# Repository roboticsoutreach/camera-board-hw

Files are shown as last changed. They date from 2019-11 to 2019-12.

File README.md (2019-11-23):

# Hardware design files for the camera module

The Camera Board is a project that aims to find a hardware replacement for webcams.

The current Webcams have a slow shutter speed and the image quality is not great, this means that the robots cannot take images while moving, and can lead to some big issues if the lighting is not right.

Using Raspberry pi camera's we can improve the shutter speed, which will hopefully allow for image processing on the move. We can also have a compute module 3 which deals with all of the image processing so that the robot "brain" doesn't have to. It will also allow for 2 cameras, one which can either be attached to the board directly or over a HDMI cable, and the other will be just over HDMI. This will allow for taking images in different directions, or having a forward facing camera and a turning camera, or could be used for stereo vision.

The first prototype for this board was made at the end of the 2018-2019 academic year, and did not work due to impedance matching issues on the HDMI lines, which meant we could not get a signal out of the Pi. This can likely be fixed by using a 4 layer stackup with a tuned impedance, this way we can ensure that the signal does not destructively interfere with itself in the cable by tuning the width of the PCB traces and the distance between the signals of a differential pair.

The Schematic has currently been updated and is now licenced under CC by SA, where previously it didn't have a license. The next step is to reoute the PCB, and order it so that a second prototype can be tested, if that works, then some of the IO will be removed, and the PCB will be made as small as possible. At this point the PCB will be ready for manufacture.

Once we have a working prototype, work will start on the software which will allow the compute module to do the image processing, and send the data over USB to the "brain" of the computer when requested. The specification and architecture of the software are not yet decided.

This project is currently being led by Joe Morton and Daniel Hobson, so if you would like to get involved with any aspect of this project, please speak to one of us.

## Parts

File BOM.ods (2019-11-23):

QTY | supplier | supplier number | link |  | price each | Qty to be ordered
8 | digikey | 490-13247-1-ND | https://www.digikey.co.uk/product-detail/en/murata-electronics-north-america/GRM188R60J476ME15D/490-13247-1-ND/5877455 | 47u | 0.32 | 20 | 6.4
16 | digikey | 1276-1000-6-ND | https://www.digikey.co.uk/product-detail/en/samsung-electro-mechanics/CL10B104KB8NNNC/1276-1000-6-ND/3891514 | 100n | 0.025 | 40 | 1
4 | digikey | 1276-1119-1-ND | https://www.digikey.co.uk/product-detail/en/samsung-electro-mechanics/CL10A106MQ8NNNC/1276-1119-1-ND/3889205 | 10u | 0.099 | 10 | 0.99
1 | digikey | 1276-7076-1-ND | https://www.digikey.co.uk/product-detail/en/samsung-electro-mechanics/CL10A226MO7JZNC/1276-7076-1-ND/7320718 | 22u | 0.62 | 4 | 2.48
2 | digikey | 1276-1036-1-ND | https://www.digikey.co.uk/product-detail/en/samsung-electro-mechanics/CL10A105KQ8NNNC/1276-1036-1-ND/3889122 | 1u | 0.022 | 10 | 0.22
12 | digikey | SML-H12P8TT86CCT-ND | https://www.digikey.co.uk/product-detail/en/rohm-semiconductor/SML-H12P8TT86C/SML-H12P8TT86CCT-ND/9090488 | LED | 0.2068 | 28 | 5.7904
2 | digikey | 475-3547-1-ND | https://www.digikey.co.uk/product-detail/en/osram-opto-semiconductors-inc/LRTBGVTG-U5V5-1-A5B5-29-S9T9-49-20-R33-B/475-3547-1-ND/8827186 | RGB LED | 0.68 | 5 | 3.4
1 | RS | 647-8263 | https://uk.rs-online.com/web/p/resettable-surface-mount-fuses/6478263/ | 2A poly fuse | 0.329 | 10 | 3.29
1 | RS | 897-1262 | https://uk.rs-online.com/web/p/pcb-terminal-blocks/8971262/ | camcon |  |  | 0
2 | digikey | 609-4050-1-ND | https://www.digikey.co.uk/product-detail/en/amphenol-icc-fci/10103594-0001LF/609-4050-1-ND/2350357 | uUSB | 0.58 | 5 | 2.9
2 | digikey | 609-1906-1-ND | https://www.digikey.co.uk/product-detail/en/amphenol-icc-fci/SFW15R-2STE1LF/609-1906-1-ND/1003189 | FFC | 0.37 | 5 | 1.85
1 | digikey | H11856CT-ND | https://www.digikey.co.uk/product-detail/en/hirose-electric-co-ltd/DF37NC-30DS-0.4V-51/H11856CT-ND/2230656 | camera connector | 0.76 | 3 | 2.28
3 | digikey | 732-2739-1-ND | https://www.digikey.co.uk/product-detail/en/wurth-electronics-inc/685119136923/732-2739-1-ND/2508681 | hdmi | 2.3 | 6 | 13.8
2 | digikey | 952-2262-ND | https://www.digikey.co.uk/product-detail/en/harwin-inc/M20-9990246/952-2262-ND/3728226 | conn | 0.08 | 4 | 0.32
1 | digikey | 732-5316-ND | https://www.digikey.co.uk/product-detail/en/wurth-electronics-inc/61300311121/732-5316-ND/4846825 | conn | 0.1 | 2 | 0.2
1 | digikey | 732-5317-ND | https://www.digikey.co.uk/product-detail/en/wurth-electronics-inc/61300411121/732-5317-ND/4846827 | conn | 0.14 | 2 | 0.28
1 | digikey | 732-5318-ND | https://www.digikey.co.uk/product-detail/en/wurth-electronics-inc/61300511121/732-5318-ND/4846831 | conn | 0.2 | 2 | 0.4
1 | digikey | 732-5319-ND | https://www.digikey.co.uk/product-detail/en/wurth-electronics-inc/61300611121/732-5319-ND/4846833 | conn | 0.26 | 2 | 0.52
1 | digikey | A26589-ND | https://www.digikey.co.uk/product-detail/en/te-connectivity-amp-connectors/3-87227-0/A26589-ND/353082 | conn | 11.32 | 2 | 22.64
2 | digikey | 445-6760-1-ND | https://www.digikey.co.uk/product-detail/en/tdk-corporation/MLZ2012N4R7LT000/445-6760-1-ND/2523581 | 4.7uH | 0.1 | 5 | 0.5
4 | digikey | 445-2986-1-ND | https://www.digikey.com/product-detail/en/MPZ1608D300BTA00/445-2986-1-ND/1084529 | ferrite | 0.079 | 10 | 0.79
1 | digikey | SDR0805-3R3MLCT-ND | https://www.digikey.co.uk/product-detail/en/bourns-inc/SDR0805-3R3ML/SDR0805-3R3MLCT-ND/3043665 | 3.3uH | 0.55 | 3 | 1.65
1 | digikey | A114854-ND | https://www.digikey.co.uk/product-detail/en/te-connectivity-amp-connectors/1473149-4/A114854-ND/1890696 | conn | 2.61 | 2 | 5.22
1 | digikey | EM6K34T2CRCT-ND | https://www.digikey.co.uk/product-detail/en/rohm-semiconductor/EM6K34T2CR/EM6K34T2CRCT-ND/5042498 | EM6K34T2CR | 0.31 | 2 | 0.62
5 | digikey | DMG1012UW-7DICT-ND | https://www.digikey.co.uk/product-detail/en/diodes-incorporated/DMG1012UW-7/DMG1012UW-7DICT-ND/2183242 | DMG1012W-7 | 0.265 | 10 | 2.65
3 | digikey | DMMT5401-FDICT-ND | https://www.digikey.co.uk/product-detail/en/diodes-incorporated/DMMT5401-7-F/DMMT5401-FDICT-ND/717881 | DMMT5401-7 | 0.34 | 6 | 2.04
3 | digikey | DMG2305UX-13DICT-ND | https://www.digikey.co.uk/product-detail/en/diodes-incorporated/DMG2305UX-13/DMG2305UX-13DICT-ND/4251589 | DMG2305UX | 0.33 | 6 | 1.98
14 | digikey | RMCF0603ZT0R00CT-ND | https://www.digikey.co.uk/product-detail/en/stackpole-electronics-inc/RMCF0603ZT0R00/RMCF0603ZT0R00CT-ND/1943218 | 0 ohm | 0.0088 | 30 | 0.264
1 | digikey | RG16P100BCT-ND | https://www.digikey.co.uk/product-detail/en/susumu/RG1608P-101-B-T5/RG16P100BCT-ND/1240831 | 100 ohm | 0.31 | 4 | 1.24
5 | digikey | YAG1235CT-ND | https://www.digikey.co.uk/product-detail/en/yageo/RT0603BRD07100KL/YAG1235CT-ND/4340588 | 100k | 0.249 | 12 | 2.988
7 | digikey | RNCP0603FTD10K0CT-ND | https://www.digikey.co.uk/product-detail/en/stackpole-electronics-inc/RNCP0603FTD10K0/RNCP0603FTD10K0CT-ND/2240478 | 10k | 0.05 | 16 | 0.8
18 | digikey | 311-470HRCT-ND | https://www.digikey.co.uk/product-detail/en/yageo/RC0603FR-07470RL/311-470HRCT-ND/730203 | 470 ohm | 0.018 | 40 | 0.72
2 | digikey | RMCF0603FT1K80CT-ND | https://www.digikey.co.uk/product-detail/en/stackpole-electronics-inc/RMCF0603FT1K80/RMCF0603FT1K80CT-ND/1943005 | 1.75k | 0.07 | 5 | 0.35
1 | digikey | RMCF0603FT27K0CT-ND | https://www.digikey.co.uk/product-detail/en/stackpole-electronics-inc/RMCF0603FT27K0/RMCF0603FT27K0CT-ND/1943083 | 27k | 0.07 | 4 | 0.28
1 | digikey | RMCF0603FT56K2CT-ND | https://www.digikey.co.uk/product-detail/en/stackpole-electronics-inc/RMCF0603FT56K2/RMCF0603FT56K2CT-ND/1943105 | 56.2k | 0.07 | 4 | 0.28
6 | digikey | 311-47.0KHRCT-ND | https://www.digikey.co.uk/product-detail/en/yageo/RC0603FR-0747KL/311-47.0KHRCT-ND/730200 | 47k | 0.018 | 15 | 0.27
1 | digikey | 450-1650-ND | https://www.digikey.co.uk/product-detail/en/te-connectivity-alcoswitch-switches/1825910-6/450-1650-ND/1632536 | tactile switch | 0.07 | 2 | 0.14
1 | digikey | 296-44844-1-ND | https://www.digikey.co.uk/product-detail/en/texas-instruments/TPS563208DDCR/296-44844-1-ND/6205060 | TPS563208 | 1.01 | 2 | 2.02
1 | digikey | PAM2306AYPKEDICT-ND | https://www.digikey.co.uk/product-detail/en/diodes-incorporated/PAM2306AYPKE/PAM2306AYPKEDICT-ND/7794266 | PAM2306AYPKE | 0.55 | 2 | 1.1
1 | digikey | LTC3406ES5-1.2#TRMPBFCT-ND | https://www.digikey.co.uk/product-detail/en/linear-technology-analog-devices/LTC3406ES5-1.2-TRMPBF/LTC3406ES5-1.2-TRMPBFCT-ND/3830391 | LTC3406ES5-1.2 | 3.53 | 2 | 7.06
1 | digikey | 296-28307-1-ND | https://www.digikey.co.uk/product-detail/en/texas-instruments/TS3DDR3812RUAR/296-28307-1-ND/2609818 | TS3DDR3812RUAR | 3.41 | 2 | 6.82
1 | digikey | 296-39282-1-ND | https://www.digikey.co.uk/product-detail/en/texas-instruments/TLV70228DBVR/296-39282-1-ND/5143273 | TLV70228 | 0.38 | 2 | 0.76
1 | digikey | 893-1140-1-ND | https://www.digikey.co.uk/product-detail/en/torex-semiconductor-ltd/XC6222B181MR-G/893-1140-1-ND/2138331 | XC6222B181MR-G | 0.66 | 2 | 1.32
1 | digikey | 497-15383-1-ND | https://www.digikey.co.uk/product-detail/en/stmicroelectronics/LSM6DS3TR/497-15383-1-ND/5180534 | LSM6DS3 | 2.25 | 2 | 4.5
1 | digikey | 497-12167-1-ND | https://www.digikey.co.uk/product-detail/en/stmicroelectronics/HDMIULC6-4SC6Y/497-12167-1-ND/2826775 | HDMIULC6-4SC6 | 1.41 | 2 | 2.82
1 | digikey | AP2331SA-7DICT-ND | https://www.digikey.co.uk/product-detail/en/diodes-incorporated/AP2331SA-7/AP2331SA-7DICT-ND/2792457 | AP2331W | 0.29 | 2 | 0.58
1 | digikey | FSUSB42UMXCT-ND | https://www.digikey.co.uk/product-detail/en/on-semiconductor/FSUSB42UMX/FSUSB42UMXCT-ND/1642629 | FSUSB42UMX | 0.44 | 2 | 0.88
1 | digikey | A118230CT-ND | https://www.digikey.co.uk/product-detail/en/te-connectivity-amp-connectors/1-292303-6/A118230CT-ND/5306349 | USB_A | 2.09 | 2 | 4.18
1 | digikey | 1473-30670-1-ND | https://www.digikey.co.uk/product-detail/en/sitime/SIT8008BI-13-18S-24.000000G/1473-30670-1-ND/7559731 | SIT8008AI-72 | 0.85 | 2 | 1.7
4 | N/A | N/A | N/A | mounting hole
2 | N/A | N/A | N/A | NF capacitor
156 |  |  |  |  |  | sub total | 125.2824
2 | Bear boards |  |  |  | 49 | 2 | 98
 |  |  |  |  |  | Overall total | 223.2824

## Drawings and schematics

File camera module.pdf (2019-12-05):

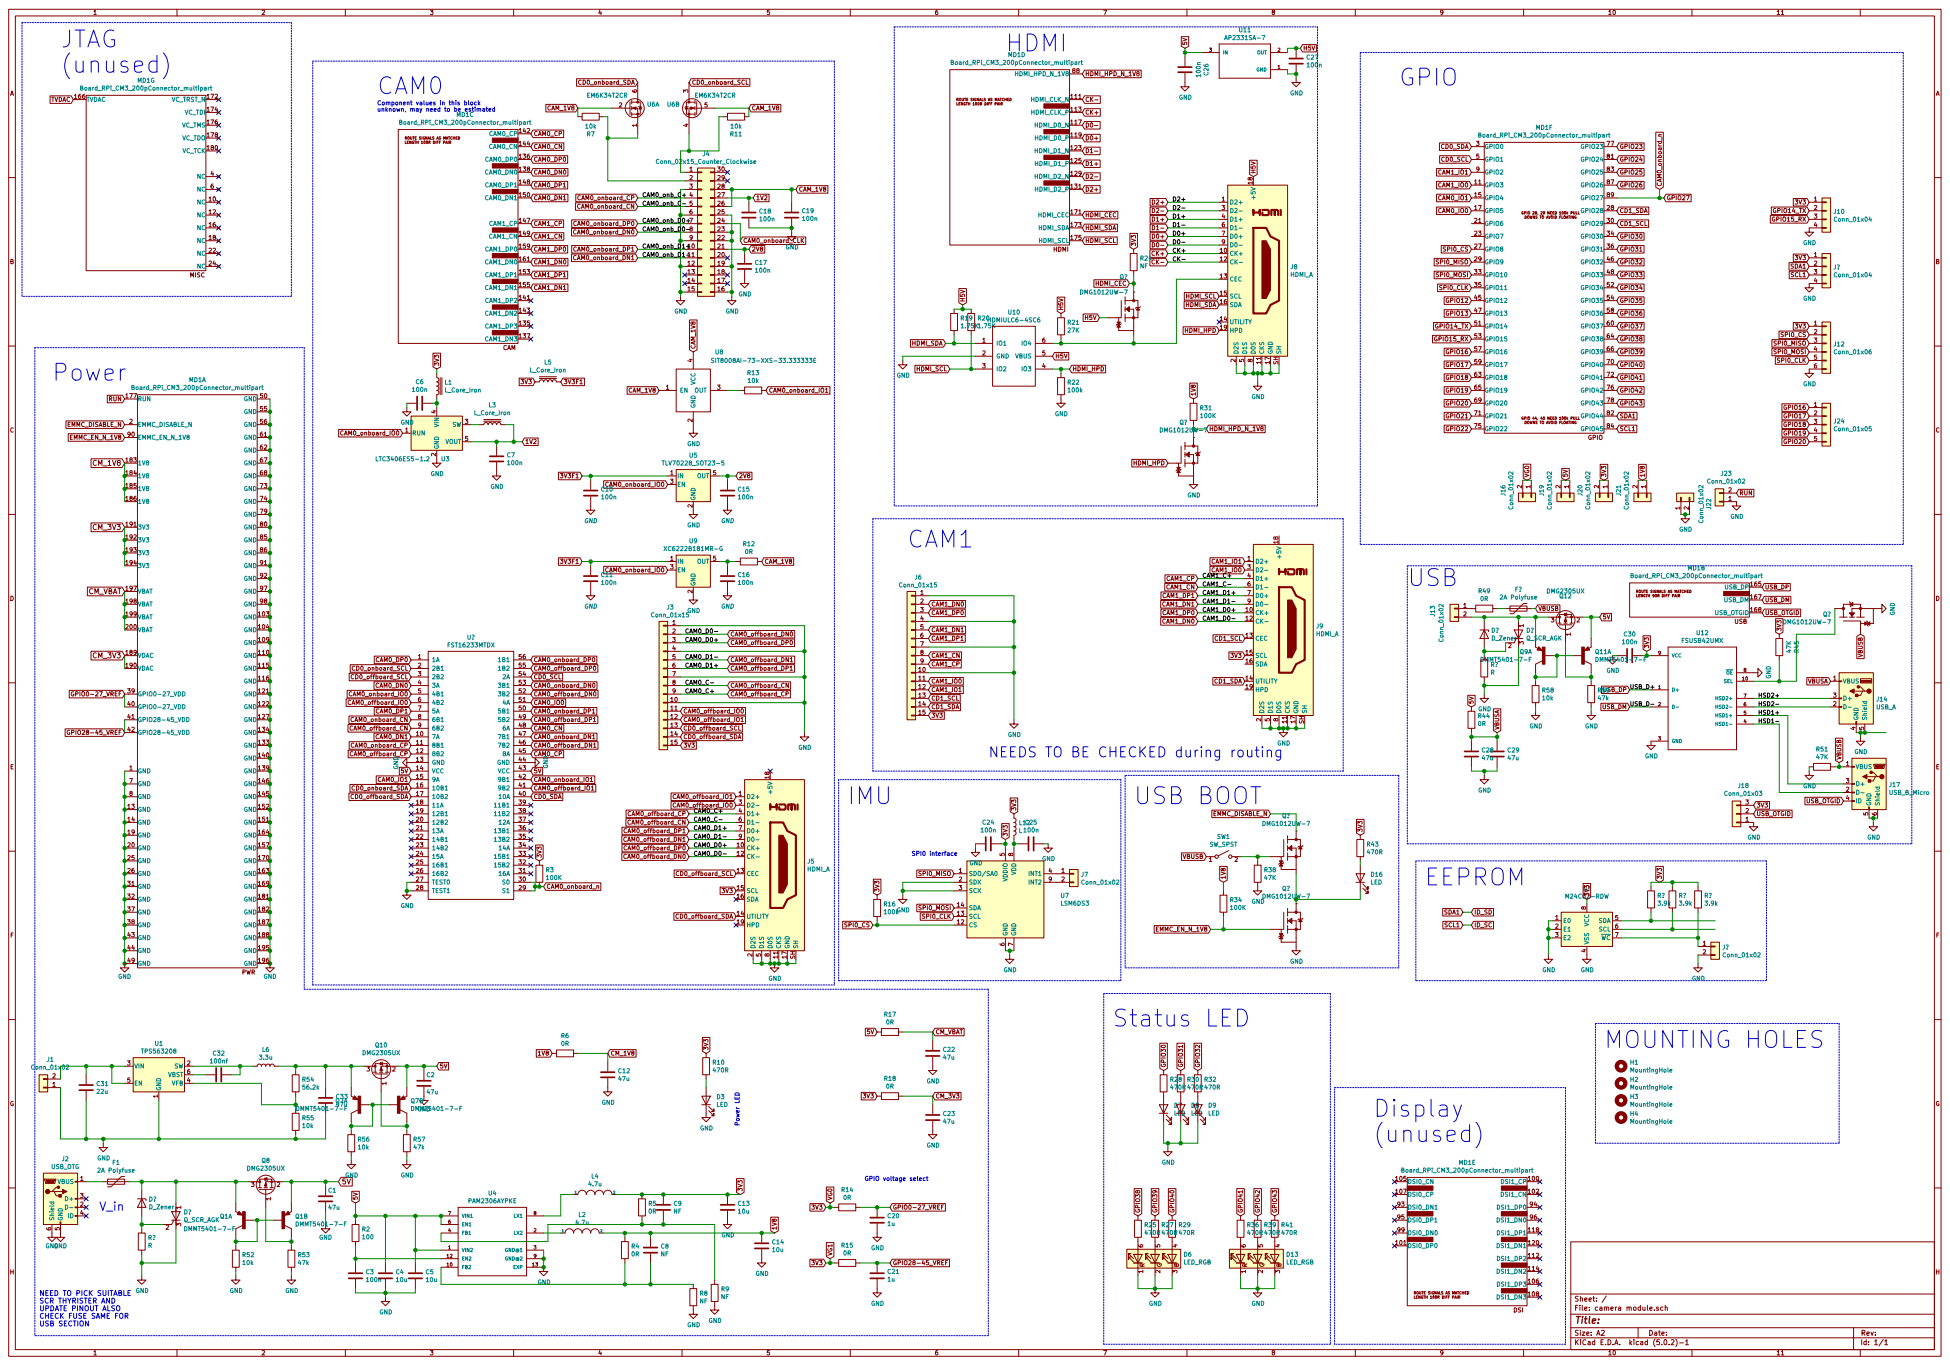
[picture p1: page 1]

GPIO 28, 29 NEED 100k PULL GPIO 44, 45 NEED 100k PULL GPIO0
5 GPIO2

Component values in this block
unknown, may need to be estimated

5 | 26
6 | 25

8 | 23
9 | 22

11 | 20
12 | 19

DOWNS TO AVOID FLOATING

1 SW 2 VIN 3 VFB 4 EN 5 VBST 6 U1 TPS563208 C31

Board_RPi_CM3_200pConnector_multipart
ROUTE SIGNALS AS MATCHED DSI0_DN1

3 D? Q_SCR_AGK NEED TO PICK SUITABLE SCR THYRISTER AND UPDATE PINOUT ALSO CHECK FUSE SAME FOR USB SECTION

DSI LENGTH 100R DIFF PAIR

Id: 1/1 Title: File: camera module.sch Sheet: /

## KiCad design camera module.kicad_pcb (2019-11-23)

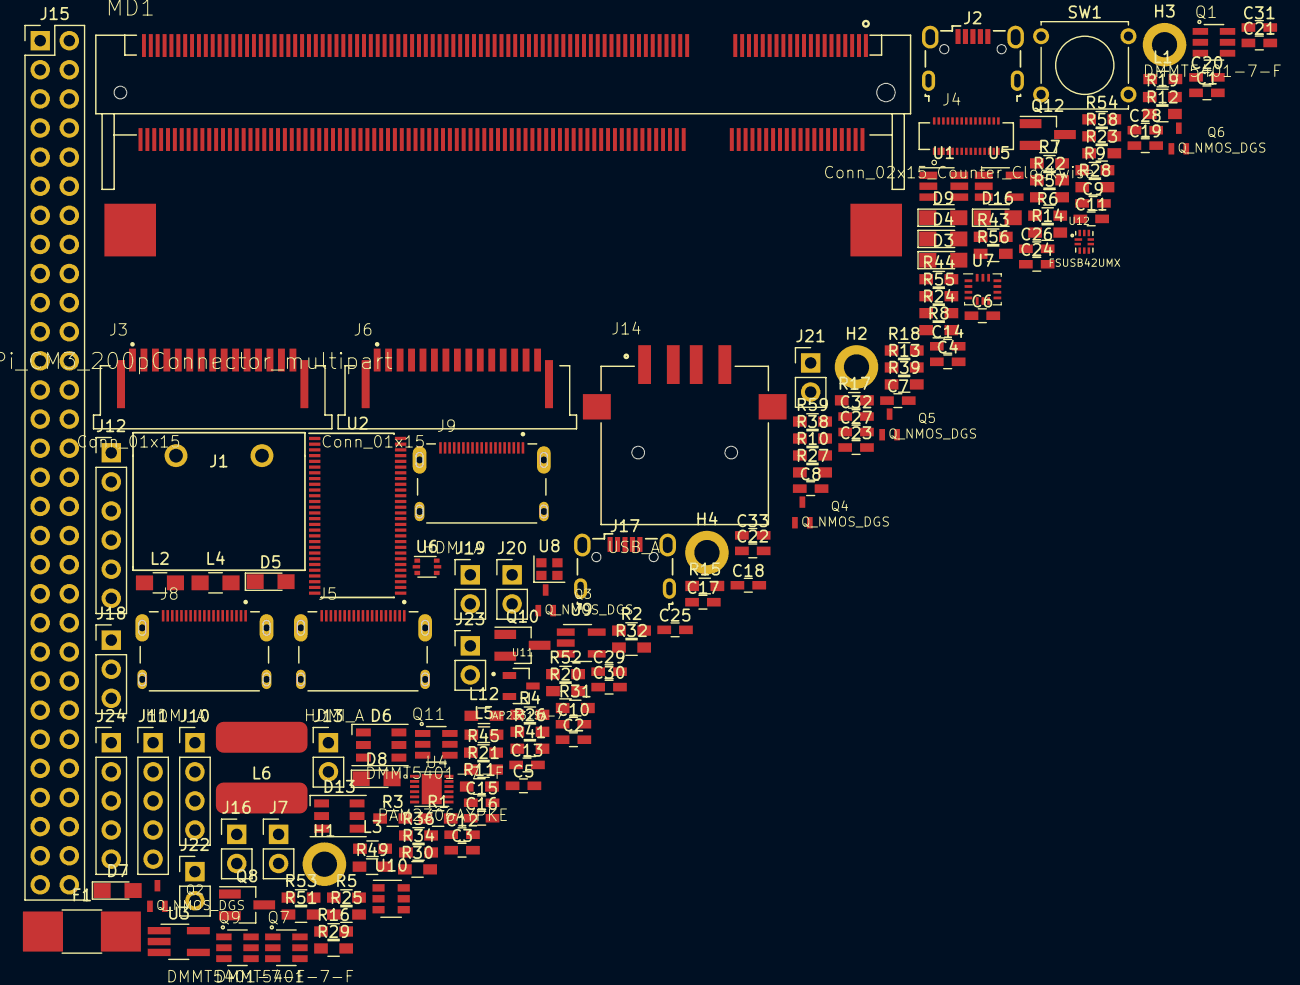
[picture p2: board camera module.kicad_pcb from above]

Board: 2 copper layers, 154 parts (0 on the bottom side), 158 nets, no tracks yet.

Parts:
C1, C2, C12, C22, C23, C28, C29, C33: 47u; C_0603_HandSoldering
C3, C6, C7, C10, C11, C15, C16, C17, C18, C19, C24, C25, C26, C27, C30: 100n; C_0603_HandSoldering
C4, C5, C13, C14: 10u; C_0603_HandSoldering
C8, C9: NF; C_0603_HandSoldering
C20, C21: 1u; C_0603_HandSoldering
C31: 22u; C_0603_HandSoldering
C32: 100nf; C_0603_HandSoldering
D3, D4, D5, D7, D8, D9, D16: LED; LED_0805_HandSoldering
D6, D13: LED_RGB; LED_RGB_PLCC-6
F1: 2A Polyfuse; L_1812_HandSoldering
H1, H2, H3, H4: MountingHole; MountingHole_2.2mm_M2_DIN965_Pad
J1: Conn_01x02; 7.5mm Camcon
J2: USB_OTG; USB_Micro-B_Wuerth-629105150521
J3, J6: Conn_01x15; AMPHENOL_SFW15R-1STE1LF
J4: Conn_02x15_Counter_Clockwise; HRS_DF37NC-30DS-0.4V(53)
J5, J8, J9: HDMI_A; WURTH_685119136923
J7, J13: Conn_01x02; Pin_Header_Straight_1x02_Pitch2.54mm
J10: Conn_01x04; Pin_Header_Straight_1x04_Pitch2.54mm
J11, J24: Conn_01x05; Pin_Header_Straight_1x05_Pitch2.54mm
J12: Conn_01x06; Pin_Header_Straight_1x06_Pitch2.54mm
J14: USB_A; TE_1-292303-6
J15: Conn_02x30_Odd_Even; Pin_Header_Straight_2x30_Pitch2.54mm
J16, J19, J20, J21, J22, J23: Conn_01x02; Socket_Strip_Straight_1x02_Pitch2.54mm
J17: USB_B_Micro; USB_Micro-B_Wuerth-629105150521
J18: Conn_01x03; Pin_Header_Straight_1x03_Pitch2.54mm
L1, L3, L5: L_Core_Iron; L_0603_HandSoldering
L2, L4: 4.7u; L_0805_HandSoldering
L6: 3.3u; SDR0805
L12: L; L_0603_HandSoldering
MD1: Board_RPi_CM3_200pConnector_multipart; TE_1473149-4
Q1, Q7, Q9, Q11: DMMT5401-7-F; SOT95P285X140-6N
Q2, Q3, Q4, Q5, Q6: Q_NMOS_DGS; SOT323
Q8, Q10, Q12: DMG2305UX; SOT-23_Handsoldering
R1, R4, R5, R6, R12, R14, R15, R17, R18, R44, R49: 0R; R_0603_HandSoldering
R2: 100; R_0603_HandSoldering
R3, R31, R34: 100K; R_0603_HandSoldering
R7, R11, R13, R52, R55, R56, R58: 10k; R_0603_HandSoldering
R8, R9, R24: NF; R_0603_HandSoldering
R10, R23, R25, R26, R27, R28, R29, R30, R32, R36, R39, R41, R43: 470R; R_0603_HandSoldering
R16, R22: 100k; R_0603_HandSoldering
R19, R20: 1.75K; R_0603_HandSoldering
R21: 27K; R_0603_HandSoldering
R38, R45, R51: 47K; R_0603_HandSoldering
R53, R57, R59: 47k; R_0603_HandSoldering
R54: 56.2k; R_0603_HandSoldering
SW1: SW_SPST; SW_Tactile_Straight_KSL0Axx1LFTR
U1: TPS563208; SOT-23-6_Handsoldering
U2: FST16233MTDX; TSSOP-56_6.1x14mm_Pitch0.5mm
U3: LTC3406ES5-1.2; TSOT-23-5_HandSoldering
U4: PAM2306AYPKE; SON45P300X300X80-13N
U5: TLV70228_SOT23-5; SOT-23-5_HandSoldering
U6: EM6K34T2CR; SOT-666
U7: LSM6DS3; Bosch_LGA-14_3x2.5mm_Pitch0.5mm
U8: SIT8008AI-73-XXS-33.333333E; Crystal_SMD_2016-4pin_2.0x1.6mm
U9: XC6222B181MR-G; SOT-23-5_HandSoldering
U10: HDMIULC6-4SC6; SOT-23-6
U11: AP2331SA-7; SOT91P240X120-3N
U12: FSUSB42UMX; IC_FSUSB42UMX

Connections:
1V2: C7.1, C18.1, J4.27, L3.2, U3.5
1V8: C8.1, C14.1, J15.12, J15.24, J15.36, J15.48, J21.1, J21.2, L2.2, R4.1, R6.2, R31.1, R34.1
2V8: C15.1, C17.1, J4.21, U5.5
3V3: C9.1, C13.1, C24.1, C30.1, J3.15, J5.15, J6.15, J9.15, J10.1, J11.1, J12.1, J15.8, J15.16, J15.20, J15.28, J15.32, J15.40, J15.44, J15.52, J16.1, J16.2, J18.3, J20.1, J20.2, L1.1, L4.2, L5.1, L12.1, R1.1, R3.1, R5.1, R10.1, R14.2, R15.2, R16.1, R18.2, R24.1, R43.1, R45.1, U7.5, U12.9
3V3F1: C10.1, C11.1, L5.2, U5.1, U9.1
5V: C1.1, C2.1, C4.1, C5.1, C26.2, J15.4, J15.56, J19.1, J19.2, Q1.5, Q7.5, Q8.2, Q10.2, Q11.6, Q12.2, R2.1, R17.2, R44.1, U2.14, U2.43, U4.1, U4.6, U4.7, U11.3
/HSD1+: J17.3, U12.5
/HSD1-: J17.2, U12.4
/HSD2+: J14.3, U12.7
/HSD2-: J14.2, U12.6
CAM0_CK: J15.13, MD1.21, U2.15
CAM0_CN: MD1.144, U2.48
CAM0_CP: MD1.142, U2.45
CAM0_DN0: MD1.138, U2.4
CAM0_DN1: MD1.150, U2.10
CAM0_DP0: MD1.136, U2.1
CAM0_DP1: MD1.148, U2.7
CAM0_IO0: J15.15, MD1.23, U2.51
CAM0_offboard_CK: J3.12, J5.1, U2.41
CAM0_offboard_CN: J3.8, J5.6, U2.9
CAM0_offboard_CP: J3.9, J5.4, U2.12
CAM0_offboard_DN0: J3.2, J5.12, U2.52
CAM0_offboard_DN1: J3.5, J5.9, U2.46
CAM0_offboard_DP0: J3.3, J5.10, U2.55
CAM0_offboard_DP1: J3.6, J5.7
CAM0_offboard_IO0: J3.11, J5.3, U2.6
CAM0_onboard_CLK: J4.24, R13.1, U2.42
CAM0_onboard_CN: J4.5, U2.8
CAM0_onboard_CP: J4.4, U2.11
CAM0_onboard_DN0: J4.8, U2.53
CAM0_onboard_DN1: J4.11, U2.47
CAM0_onboard_DP0: J4.7, U2.56
CAM0_onboard_DP1: J4.10, U2.50
CAM0_onboard_IO0: U2.5, U3.1, U5.3, U9.3
CAM0_onboard_n: MD1.89, R3.2, U2.29, U2.30
CAM1_CK: J6.12, J9.1
CAM1_CLK: J11.2, J15.5
CAM1_CN: J6.8, J9.6, MD1.149
CAM1_CP: J6.9, J9.4, MD1.147
CAM1_DN0: J6.2, J9.12, MD1.161
CAM1_DN1: J6.5, J9.9, MD1.155
CAM1_DP0: J6.3, J9.10, MD1.159
CAM1_DP1: J6.6, J9.7, MD1.153
CAM1_IO0: J6.11, J9.3, J11.3, J15.7
CAM_1V8: C19.2, J4.26, J4.28, R7.2, R11.1, R12.1, U6.2, U6.5, U8.1, U8.4
CD0_SCL: J15.11, MD1.17, U2.54
CD0_SDA: J11.4, J15.9, U2.40
CD0_offboard_SCL: J3.13, J5.13, U2.3
CD0_offboard_SDA: J3.14, J5.14, U2.17
CD0_onboard_SCL: U2.2, U6.3
CD0_onboard_SDA: U2.16, U6.6
CD1_SCL: J6.13, J9.13, J15.3, MD1.5
CD1_SDA: J6.14, J9.14, J15.1, MD1.3
CK+: J8.10, MD1.113
CK-: J8.12, MD1.111
CM_1V8: C12.1, MD1.183, MD1.184, MD1.185, MD1.186, R6.1
CM_3V3: C23.1, MD1.189, MD1.190, MD1.191, MD1.192, MD1.193, MD1.194, R18.1
CM_VBAT: C22.1, MD1.197, MD1.198, MD1.199, MD1.200, R17.1
D0+: J8.7, MD1.119
D0-: J8.9, MD1.117
D1+: J8.4, MD1.125
D1-: J8.6, MD1.123
D2+: J8.1, MD1.131
D2-: J8.3, MD1.129
EMMC_DISABLE_N: MD1.2, Q4.1
EMMC_EN_N_1V8: MD1.90, Q5.2, R34.2
GND: C1.2, C2.2, C3.2, C4.2, C5.2, C6.2, C7.2, C10.2, C11.2, C12.2, C13.2, C14.2, C15.2, C16.2, C17.2, C18.2, C19.1, C20.1, C21.1, C22.2, C23.2, C24.2, C25.1, C26.1, C27.2, C28.2, C29.2, C30.2, C31.2, C33.2, D3.1, D4.1, D5.1, D6.1, D6.2, D6.3, D7.1, D8.1, D9.1, D13.1, D13.2, D13.3, J1.1, J2.5, J2.6, J3.1, J3.4, J3.7, J3.10, J4.3, J4.6, J4.9, J4.12, J4.15, J4.16, J4.19, J4.22, J4.23, J4.25, J5.2, J5.5, J5.8, J5.11, J5.17, J5.SH, J6.1, J6.4, J6.7, J6.10, J8.2, J8.5, J8.8, J8.11, J8.17, J8.SH, J9.2, J9.5, J9.8, J9.11, J9.17, J9.SH, J10.4, J11.5, J12.6, J14.4, J14.5, J15.2, J15.6, J15.10, J15.14, J15.18, J15.22, J15.26, J15.30, J15.34, J15.38, J15.42, J15.46, J15.50, J15.54, J15.58, J15.60, J17.5, J17.6, J18.1, J22.1, J22.2, J23.1, MD1.1, MD1.7, MD1.8, MD1.13, MD1.14, MD1.19, MD1.20, MD1.25, MD1.26, MD1.31, MD1.32, MD1.37, MD1.38, MD1.43, MD1.44, MD1.49, MD1.50, MD1.55, MD1.56, MD1.61, MD1.62, MD1.67, MD1.68, MD1.73, MD1.74, MD1.79, MD1.80, MD1.85, MD1.86, MD1.91, MD1.92, MD1.97, MD1.98, MD1.103, MD1.104, MD1.109, MD1.110, MD1.115, MD1.116, MD1.121, MD1.122, MD1.127, MD1.133, MD1.134, MD1.139, MD1.140, MD1.145, MD1.146, MD1.151, MD1.152, MD1.157, MD1.163, MD1.164, MD1.169, MD1.170, MD1.181, MD1.182, MD1.187, MD1.188, MD1.195, MD1.196, Q3.3, Q5.3, Q6.3, R8.2, R9.2, R22.2, R38.2, R51.2, R52.2, R53.2, R55.2, R56.2, R57.2, R58.2, R59.2, U1.1, U2.13, U2.27, U2.28, U2.44, U3.2, U4.3, U4.9, U4.13, U5.2, U7.2, U7.3, U7.6, U7.7, U8.2, U9.2, U10.2, U11.1, U12.3, U12.8
GPIO0-27_VREF: C20.2, MD1.39, MD1.40, R14.1
GPIO12: J15.25, MD1.45
GPIO13: J15.27, MD1.47
GPIO14_TX: J10.2, J15.29, MD1.51
GPIO15_RX: J10.3, J15.31, MD1.53
GPIO16: J15.33, J24.1, MD1.57
GPIO17: J15.35, J24.2, MD1.59
GPIO18: J15.37, J24.3, MD1.63
GPIO19: J15.39, J24.4, MD1.65
GPIO20: J15.41, J24.5, MD1.69
GPIO21: J15.43, MD1.71
GPIO22: J15.45, MD1.75
GPIO23: J15.47, MD1.77
GPIO24: J15.49, MD1.81
GPIO25: J15.51, MD1.83
GPIO26: J15.53, MD1.87
GPIO28: MD1.28, R23.1
GPIO28-45_VREF: C21.2, MD1.41, MD1.42, R15.1
GPIO29: MD1.30, R26.1
GPIO30: MD1.34, R28.1
GPIO31: MD1.36, R30.1
GPIO32: MD1.46, R32.1
GPIO38: MD1.64, R25.1
GPIO39: MD1.66, R27.1
GPIO40: MD1.70, R29.1
GPIO41: MD1.72, R36.1
GPIO42: MD1.76, R39.1
GPIO43: MD1.78, R41.1
H5V: C27.1, J8.18, Q2.2, R19.1, R20.1, R21.1, U10.5, U11.2
HDMI_CEC: MD1.171, Q2.1, R24.2
HDMI_HPD: J8.19, Q3.2, R22.1, U10.4
HDMI_HPD_N_1V8: MD1.88, Q3.1, R31.2
HDMI_SCL: J8.15, MD1.175, R20.2, U10.3
HDMI_SDA: J8.16, MD1.173, R19.2, U10.1
unnamed: C3.1, R2.2, U4.12
unnamed: C6.1, L1.2, U3.4
unnamed: C8.2, R4.2, R8.1, U4.10
unnamed: C9.2, R5.2, R9.1, U4.4
unnamed: C16.1, R12.2, U9.5
unnamed: C25.2, L12.2, U7.8
unnamed: C31.1, J1.2, U1.3, U1.5
unnamed: C32.1, L6.1, U1.2
unnamed: C32.2, U1.6
unnamed: C33.1, L6.2, Q7.6, Q10.3, R54.1
unnamed: D3.2, R10.2
unnamed: D4.2, R23.2
unnamed: D5.2, R26.2
unnamed: D6.4, R29.2
unnamed: D6.5, R27.2
unnamed: D6.6, R25.2
unnamed: D7.2, R28.2
unnamed: D8.2, R30.2
unnamed: D9.2, R32.2
unnamed: D13.4, R41.2
unnamed: D13.5, R39.2
unnamed: D13.6, R36.2
unnamed: D16.1, Q4.3, Q5.1
unnamed: D16.2, R43.2
unnamed: F1.1, Q1.6, Q8.3
unnamed: F1.2, J2.1
unnamed: J4.1, R11.2, U6.4
unnamed: J4.2, R7.1, U6.1
unnamed: J7.1, U7.4
unnamed: J7.2, U7.9
unnamed: J8.13, Q2.3, R21.2, U10.6
unnamed: J13.1, R49.2
unnamed: J13.2, Q9.6, Q12.3
unnamed: L2.1, U4.2
unnamed: L3.1, U3.3
unnamed: L4.1, U4.8
unnamed: MD1.4, MD1.6, R1.2
unnamed: Q1.1, Q1.2, Q1.3, R52.1
unnamed: Q1.4, Q8.1, R53.1
unnamed: Q4.2, R38.1, SW1.2
unnamed: Q6.1, R45.2, U12.10
unnamed: Q7.1, Q7.2, Q7.3, R56.1
unnamed: Q7.4, Q10.1, R57.1
unnamed: Q11.1, Q12.1, R59.1
unnamed: Q9.1, Q9.2, Q11.2, R58.1
unnamed: R13.2, U8.3
unnamed: R54.2, R55.1, U1.4
RUN: J15.57, J23.2, MD1.177
SPI0_CLK: J12.5, J15.23, MD1.35, U7.13
SPI0_CS: J12.2, J15.17, MD1.27, R16.2, U7.12
SPI0_MISO: J12.3, J15.19, MD1.29, U7.1
SPI0_MOSI: J12.4, J15.21, MD1.33, U7.14
USB_DM: MD1.167, U12.2
USB_DP: MD1.165, U12.1
USB_OTGID: J17.4, J18.2, MD1.168
VBUSA: C28.1, C29.1, J14.1, R44.2
VBUSB: J17.1, Q6.2, R49.1, R51.1, SW1.1

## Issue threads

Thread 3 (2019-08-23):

make a release V0

joe9599, 2019-08-23:
the prototype that was made should be our first release, so that we know what stage it was at when it was made

trickeydan, 2019-08-23:
This should be done using a GitHub release.

On the main page of the repo, click on releases and then "Draft Release".

You can then add a description, version number etc. Make sure to select the commit of the version that we manufactured.

joe9599, 2019-08-23:
Yeah, that's what I was going to do, but didn't have access

trickeydan, 2019-08-23:
Query: Why `v0`? Surely it makes more sense to start at Rev 1?

joe9599, 2019-08-23:
I was thinking 0 as it is a non working protoype

trickeydan, 2019-08-23:
Have done some research:

```
We handle it the following way: Major.Minor.Revision

Major is changed, if there were changes to board dimensions or extensive changes to component placement or general functionality. Like re-designing a PCB for a different enclosure or adding a new connector.

Minor is changed, if there were any changes to component placement, routing, copper fills etc. Essentially any change, that potentially changes electrical characteristics.

Revision represents the revision number from our version control system (Subversion) and thus increases with every committed change. This could be a small change to the silkscreen or changing component types/values due to better availability. Versions with a revision changes only can be processed by the assembly house without any adjustments (paste mask compatible, same dimensions, same pick&place).

Version progression: If Major is incremented, Minor resets to 0. Revisions always increments and unambiguously identifies a specific version. Example: 1.0.0 -> 1.0.1 -> 1.0.2 -> 1.1.3 -> 2.0.4

Relevance to part list: Our BOM contains a reference to the Major.Minor version of the compatible target PCB. The revision is not relevant with respect to the PCB, since there were no relevant physical changes. Thus, 1.2.10 can be assembled just like 1.2.15. The BOM itself has a revision number, that is equal or higher than the target PCB version. Example: A BOM titled "BOM 1.2.18 - Target PCB 1.2" can be used to assemble boards of version 1.2.10 as well as 1.2.15.
```

I think this summarises a good scheme for naming board revisions. However it doesn't solve the thing we're discussing. I'd be happy with a `v0.0.1` etc.

joe9599, 2019-08-23:
The way we do it at work is major.minor, major is incremented when something is to be shipped, else minor is incremented, but that adds an unnecessary step of changing silkscreen anytime we want to commit anything, as the version number should be printed on the pc
In the above case, the minor I described is the same as your revision, and major combines your major and minor (I think this is better, because especially with the camera board, the way it's routed is a major change, due to time critical traces)

joe9599, 2019-08-23:
Ultimately we can figure out the details later, I just want to work on the next version, so need to make a release so that we know the state of the design at this build

Closed 2019-08-26.

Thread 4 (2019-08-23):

fix HDMI routing

joe9599, 2019-08-23:
the HDMI routing needs to be redone so that the traces are the right length relative to each other

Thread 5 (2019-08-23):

reduce BOM cost

joe9599, 2019-08-23:
there are a number of overly expensive components, which can be respeced for cheaper versions (e.g. the analogue switch on Cam 1

joe9599, 2019-08-26:
The header is very expensive, but wont be needed (we wont break out as many GPIO in the next prototype) this removes digikey part A26589-ND (which cost >£11)

joe9599, 2019-08-26:
The camera switch chip (Digikey 296-28307-1-ND) can be replaced with https://uk.rs-online.com/web/p/multiplexer-switch-ics/8076068/ and a mosfet (saving ~£3)

joe9599, 2019-08-26:
the cost of the final version will be cheaper by the nature of not having all the debug outputs (GPIO broken out, less HDMI ports, one of the USB ports wont be needed, A LOT LESS OF LEDs) as well as buying components in bulk to get them cheaper per part (this will be particularly relevant with caps (which we can make smaller when we are happy that we dont need to modify them by hand)

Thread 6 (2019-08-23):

Licensing

trickeydan, 2019-08-23:
We should add an appropriate (preferably open source) licence to this repo.

joe9599, 2019-08-23:
V0 has some libraries that conflict with licences (due to speed and lack of licencing knowledge the second of which is still an issue), this will be fixed an licenced in v1

joe9599, 2019-09-17:
All libraries are now either standard Kicad libraries, CC by SA, or made by me, so when these changes are checked in, the license can be sorted

trickeydan, 2019-09-17:
Ok, so due to the nature of the CC-By-SA licence, we will need to use that in order to comply. From what I can tell, specifically CC-BY-SA 4.0

I'll make a PR.

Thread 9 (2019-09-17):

wrong footprints

joe9599, 2019-09-17:
DMG1012UW-7 uses the wrong footprint in the first version of the hardware (SDG vs DGS) the schematic symbol needs to be changed to match

joe9599, 2019-09-17:
The symbols have been updated

Closed 2019-09-17.

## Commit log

2019-02-18 My first commit, I hope I didn't screw stuff up
    [camera module.sch]
2019-02-18 Joe crashed KiCAD, not my fault
    [camera module-2019-02-06-21-17-37.sch, camera module.kicad_pcb, camera module.sch]
2019-02-20 Tweaks to routing, 4th mounting hole added, DRC issues fixed
    [camera module.kicad_pcb, camera module.sch]
2019-02-25 Via for GND on mux moved, ready for checking
    [camera module.kicad_pcb]
2019-03-11 Final files. As sent to manufacture
    [camera module-B.Cu.gbr, camera module-B.Mask.gbr, camera module-B.Paste.gbr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]
2019-03-15 Added some vias to replace plated slots, removed a couple of stray tracks
    [camera module.kicad_pcb]
2019-03-18 Added missing outline on edgecuts layer(!)
    [camera module.kicad_pcb]
2019-03-25 Added BOM, started ticking off parts that arrived
    [bom.xlsx]
2019-03-26 BOM checked against recieved parts and ommisions noted
    [bom.xlsx]
2019-05-01 update BOM, now finished
    [bom.xlsx]
2019-05-01 Remove windows file paths in symbol libraries
    [camera module-2019-02-06-21-17-37.sch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]
2019-09-24 fixing library structure
    [bom.xlsx]
2019-09-24 Uploaded the start of V1
    libraries are now compliant with license, and schematic has been slightly changed to be cheaper, MOSFET footprints also fixed
    [BOM.ods, camera module.kicad_pcb]
2019-12-05 A few small changes and fixes
    [camera module.sch]
